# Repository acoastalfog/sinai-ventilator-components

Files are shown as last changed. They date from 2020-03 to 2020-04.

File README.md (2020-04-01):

**CURRENT VERSION: [v1.3](https://github.com/acoastalfog/sinai-ventilator-components/blob/master/v1.3). Instructions in the current version's folder should be followed, together with the supplied protocol.**

**NOTE 2020-04-01: *We have split version tracking in this project into folders. Each version contains its own `README.md` file, together with the Mount Sinai protocol, STEP, STL, and Fusion360 component files, prototyping instructions, and walk-throughs.***

# Mount Sinai Health System Split Ventilator Prototyping
The Sinai BioDesign Group at the Mount Sinai Health System is supporting ongoing work by the Department of Anesthesia's team to develop a robust and validated protocol for ventilator splitting at the Mount Sinai Hospital System. Our support is mainly in the design and prototyping of components for the split ventilator system.

Our contributions are for academic study only and we do not endorse their use in any medical application. We are making them available to the community in order to scale out prototyping and research of these components. We are making available our designs together with STEP and Fusion360 files if others choose to take what we have done and modify, and will continually update this page.

Any included protocols are not final, pose significant risks to both patients sharing a single ventilator and do not in any way reflect the normal standard of care within the Mount Sinai Health System. Protocols have not yet been trialed in patients. They are included for academic purposes and for implementation in high-fidelity human patient simulator laboratory settings.

We are following the versioning scheme developed by the Anesthesia team, and we will update the head of this document with the most up to date versions as they become available, together with paired prototyping files and instructions. Most components developed a set of valves and adapters for printing on ordinary, widely available FDM-style 3D printers, commonly found in makerspaces, institutional prototyping facilities, and home labs. Variations and opportunities to use alternate prototyping tools, and versioned branches of the protocol, will also be tracked.

## Sinai BioDesign Team Members
* Joe Borrello
* Jake Wolf
* Anthony Costa

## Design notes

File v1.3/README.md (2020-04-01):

**NOTE 2020-04-01: *We have validated the adapter components against multiple gate and needle valve configurations of the current and future protocols from the anesthesia team. Adapter components should now be printed.***

**NOTE 2020-04-01: *Added optional laser-cut plastic membrane [cut files](membrane) and [instructions](buildPlasticMembrane.md).***

**NOTE 2020-03-31: *Added detailed check valve assembly instructions [here](buildCheckValve.md).***

~~NOTE 2020-03-30: Please as of this moment only produce the one-way check-valve components until further notice. It is likely that our gate valve will change due to regulatory requirements, so adapters must be modified or may become obsolete. The check valve is independent of the gate and has been approved.~~

# Mount Sinai Health System Split Ventilator Prototyping
Version 1.3

Here, we are making available two simple-to-print flow adapters (in folder [adapter](adapter)), together with a one-way check valve (in folder [check_valve](check_valve)). The check valve is a heavily modified version of an existing open source project, with original project documentation, [build instructions](https://youtu.be/sCIX3egYKQM), and [project files](https://cad.onshape.com/documents/5c996e71d2872726995198bf/w/40c80b6ee82124a954fda09d/e/5520dc2a611624c9350b6dc1) also publicly available. We thank these teams for their effort. 

## Basic Build Information
* Both sets of parts below should be printed in PLA with a layer height between 0.1 and 0.3mm. We encourage you to print at the largest layer height possible and checking for press-fit and thread compatibility for the adapter and check valve, respectively.
* Print with at least 3 perimeters and at least 3 top and bottom layers.
* Infill of 10-20% is more than sufficient for appropriate rigidity. 
* PLA including additives *should not be used*. Other materials can be considered. PETG seems a particularly good option for dimensional accuracy, though this has not yet been tested. ABS should not be used.
* Depending on your cooling capacity you may not require any supports, but your mileage may vary. `adapter_v1.3_smallMaleMale.stl` and `valve_v1.3_Female.stl` both include a 90 degree overhang when printed in the correct orientation. Setting the overhang angle to 75 degrees will eliminate unnecessary support structures being generated for threading in each of the valve components.
* Press-fit interfaces between adapters and valves should be lined with teflon tape.

These designs have been fit tested from prints on at least 6 commonly available FDM-style 3D printers, with good intra-printer reliability. For use, prints from the same printer should be paired. The entire set of files has been parameterized around the fit of the male interface to a commonly-available [3/4" brass sweat gate valve](https://www.homedepot.com/p/Everbilt-3-4-in-Brass-Sweat-x-Sweat-Gate-Valve-170-4-34-EB/308593230).

## Inner (Male-Male) and Outer (Female-Female) Flow Adapters

**NOTE: 2020-04-01: *We have validated the adapter components against multiple gate and needle valve configurations of the current and future protocols from the anesthesia team. Adapter components should now be printed.***

~~NOTE 2020-03-30: Please do not yet produce this part. It is likely that our gate valve will change due to regulatory requirements, so adapters must be modified or may become obsolete.~~

* Files are `adapter_v1.3_largeFemaleFemale.stl` and `adapter_v1.3_smallMaleMale.stl`.
* Files should be printed in a vertical orientation, but are symmetric along this axis with a normal plane of symmetry, so either orientation is equivalent. 

## Two-Part One-Way Check Valve
* Files are `valve_v1.3_Female.stl` and `valve_v1.3_Male.stl`, and can be printed in ordinary PLA.
* Print orientation here *matters*. `valve_v1.3_Male.stl` must be printed with the threading down toward the build surface, preferably made of glass or other very smooth material. It is important that this interface is as smooth as possible.
* `valve_v1.3_Female.stl` should be printed with threads up, as this eliminates unnecessary support structures inside the thread cavity, requiring them only for the 90 degree overhang.
* Build instructions are now available as a [separate document](buildCheckValve.md).
* We include laser-cut plastic membrane [cut files](membrane) and [instructions](buildPlasticMembrane.md) as an assembly option, referenced in the build instructions for the check valve.

Appropriate orientation on the build plate is shown here.

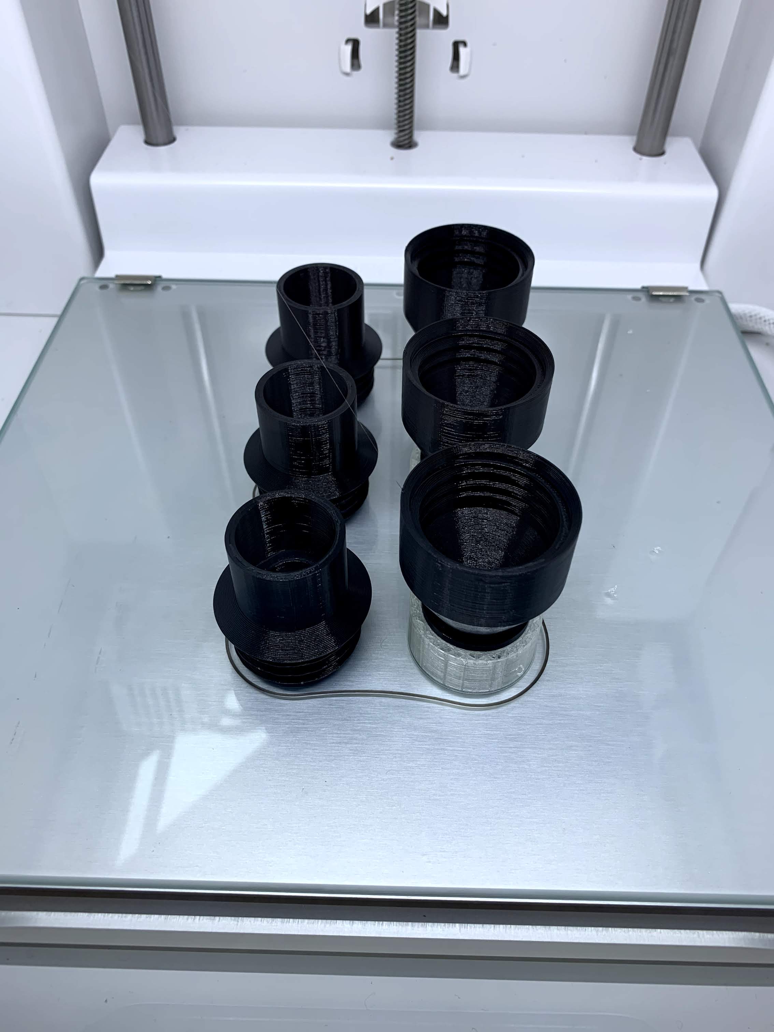
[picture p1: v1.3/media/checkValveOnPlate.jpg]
Check Valve On Glass Build Plate


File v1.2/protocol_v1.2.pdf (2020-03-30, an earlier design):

## Mount Sinai Health System Emergency Ventilator Sharing Protocol

The protocol described in this document is a work in progress and is subject to revision

Version 1.2
Version Date: March 28, 2020

Protocol Developed By:
Martin Chen MD
Anjan Shah MD
Ronak Shah MD
George Zhou MD
Erica Kane MD, MPH
Garrett Burnett MD
Chang Park MD
Daniel Katz MD
Shams Ranginwala MBA, RRT-NPS, CPFT
Matthew Levin MD

We would like to acknowledge the team and protocol developed at Columbia/NYP which served as a template and guide for this document.

Purpose: This document describes the implementation of a shared (also referred to herein as split) ventilator protocol for the Mount Sinai Health System (MSHS). It would be utilized when enacting Crisis Standards of Care at hospitals within the MSHS, when rescuable patients who require mechanical ventilation would otherwise be denied ventilation due to lack of available ventilators. This protocol poses significant risks to both patients sharing a single ventilator and does not in any way reflect the normal standard of care within the MSHS. It has been developed in response to the unique situation caused by the COVID-19 Crisis in New York City. Each patient should be mechanically ventilated individually, unless the supply of ventilators is completely exhausted and the patient would otherwise be expected to die.

Version 1.2 2020-03-29 | 1

DISCLAIMER: This shared ventilator protocol has not yet been trialed in patients. The study was designed and conducted in the Department of Anesthesiology, Perioperative and Pain Medicine’s high-fidelity human patient simulator laboratory using two CAE HPS Anesthesia Simulator Mannequin Systems (CAE Healthcare, Sarasota, Florida). The parameters were determined experimentally.

Patient selection: Criteria for split ventilation will likely be adaptive given the emergent circumstances, but if possible the following criteria should be satisfied:
1. Both patients are Covid-19 patients, in order to avoid infection.
2. Patients should be paired according to ideal body weight.
3. Patients should have initial similar lung compliances and levels of ventilatory support
4. Patients should require similar levels of PEEP.
5. Patients should be predicted to require mechanical ventilation with paralysis for > 72 hours.

Design Overview: The ventilator breathing circuit is split using standard T-pieces and connectors. On the inspiratory limb, two standard ¾” brass lead-free gate valves (normally used in plumbing applications) are placed in-line on either side of a T-piece. The connections on the ¾” valve have an internal diameter (ID) of approximately 22 mm. On the expiratory limb, two unidirectional valves are placed on two sides of another T-piece. Near the patient, a standard spirometry sensor is placed in-line between the endotracheal tube elbow and the wye connector of the breathing circuit. The sensor is connected to the gas analyzer-spirometry module of a portable or stationary physiologic monitoring system . Due to the nature of the pandemic, a bacterial/viral (B/V) filter is placed between the elbow and the endotracheal tube, and additional B/V filters are placed between the circuit and the inspiratory and expiratory connection ports on the ventilator.

Improvements over other solutions:
1. The ¾” gate valves allow the pressure and volume delivered to each patient to be adjusted and titrated to account for the potentially different lung compliance (stiffness) of each patient.

2. The use of appropriately placed spirometry sensors enables more accurate measurement of the delivered tidal volume and pressures for each patient individually. Spirometry and gas analysis data can be displayed on a wall-mounted or portable monitor, provided that a spirometry-gas analyzer module can be installed in the physiologic monitoring system.
3. The unidirectional valves in the expiratory limbs prevent reverse flow of gas in the circuits.

The ¾” valves used are brass, lead-free standard plumbing valves that are certified for use in domestic water supply applications. These brass valves are heavy, so ensure that the connections are gas-tight using teflon tape and secure the valves to the ventilator.

DISCLAIMER: The use of these valves for a medical application is not approved in any way and is a significant deviation from standard of care. The valves MUST be cleaned to remove obvious manufacturing contaminants such as oil, grease, dirt, etc. Our protocol was to clean by hand using soap and a brush, then place through a steam sterilization cycle. As per CDC guidelines, peracetic acid and hydrogen peroxide should be avoided due to the issue of brass corrosion.

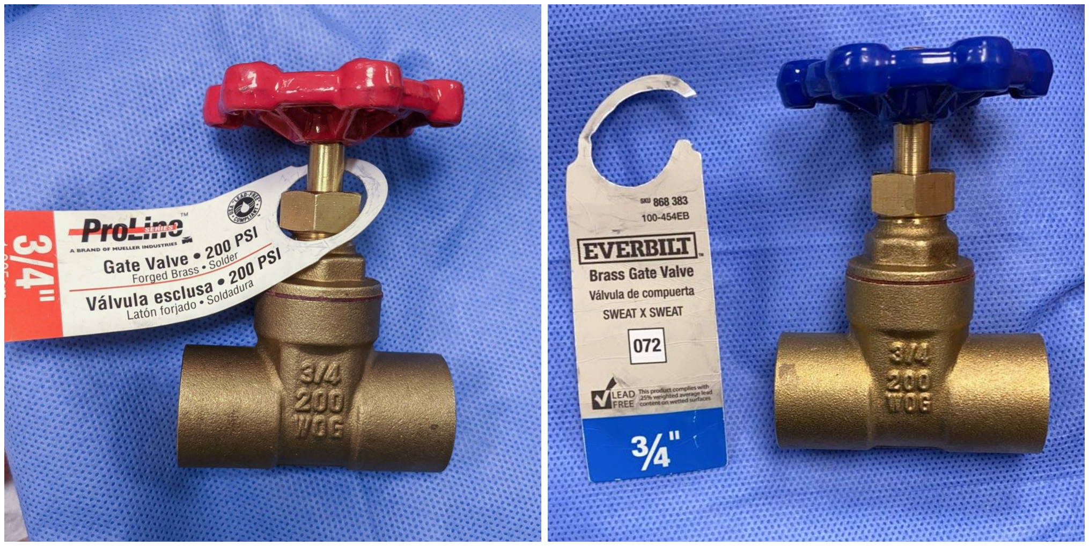
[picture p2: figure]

Figure 1A - Part #1, listed below. Example ¾” brass gate valves with solder/sweat connections. PVC alternatives are available, but were not tested due issues with valve performance.

Parts List
1. 2x ¾” ID lead-free brass gate valves with “sweat” or “solder” connections for the inspiratory limbs. These should be available from Home Depot, Lowes, or any plumbing supply store.
2. 2x in-line, unidirectional valves for breathing circuit’s expiratory limbs (Mallinckrodt One-way valve, 22mm F x 22mm M)
3. 2x T-pieces, 15mm ID/22mm OD to 2x 19mm ID/22mm OD (Hudson RCI Trache Tee Oxygenator)
4. 4x 22mm OD, 15 mm ID both ends (male-to-male) adapter (blue Airlife Intubation Adapter 001820)
5. 2x 22mm ID female-to-female adapter (clear Mallinckrodt Universal Cuff Adapter)
6. 2x ventilator circuits
7. 2x yellow spirometry sensor and tubing (GE D-lite++ patient spirometry set; GE part number 2102497-002- 3 meter length tubing)
8. 2x Bacterial/Viral (B/V) filters (placed near ETT and in expiratory limb)
9. 2x Heat and Moisture Exchanger Filters (HME Filter)
10. Spirometry module/monitor (GE Carescape Respiratory Module)
11. Teflon plumbing threadseal tape (required for metal joints)
12. Electrical tape

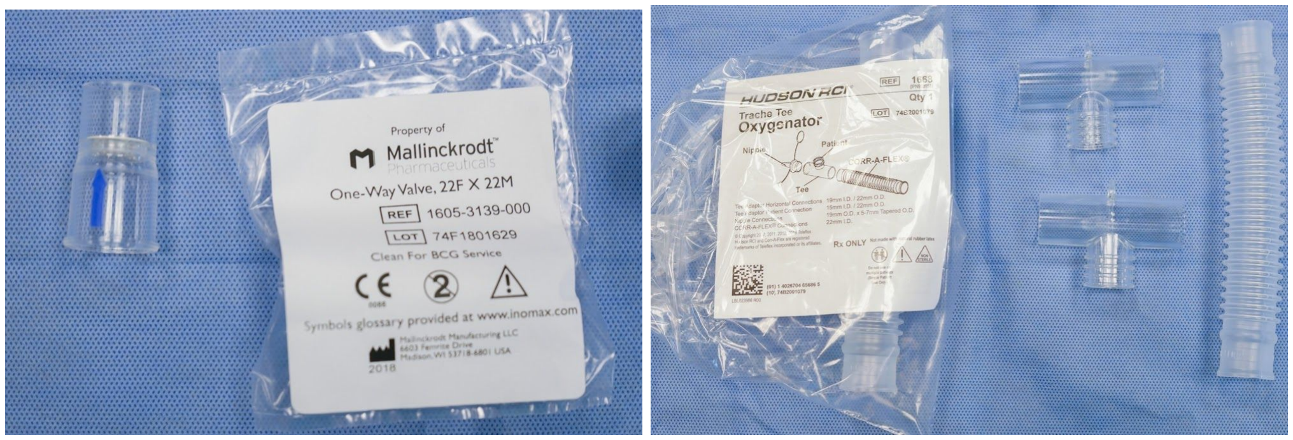
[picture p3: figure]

Figure 1B. Part #2 and #3, listed above.

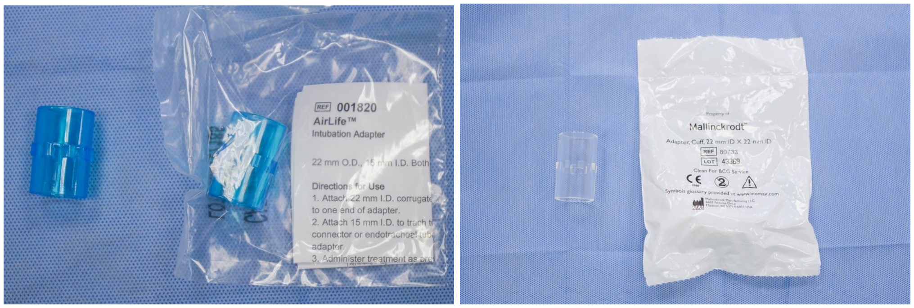
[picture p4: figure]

Figure 1C. Part #3 and #4, listed above.

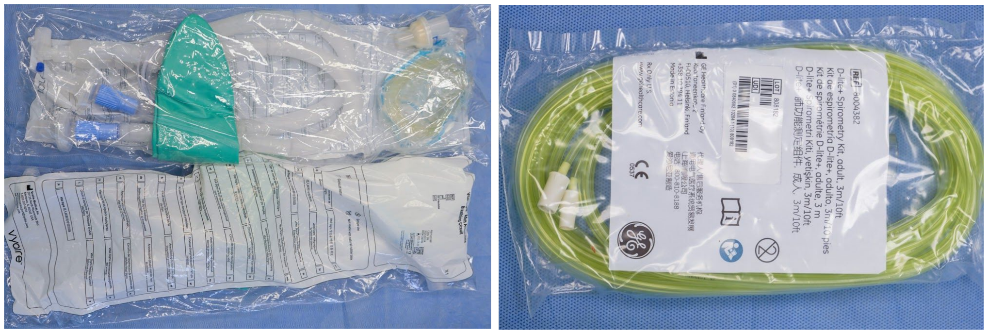
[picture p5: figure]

Figure 1D. Part #6 and #7, listed above.

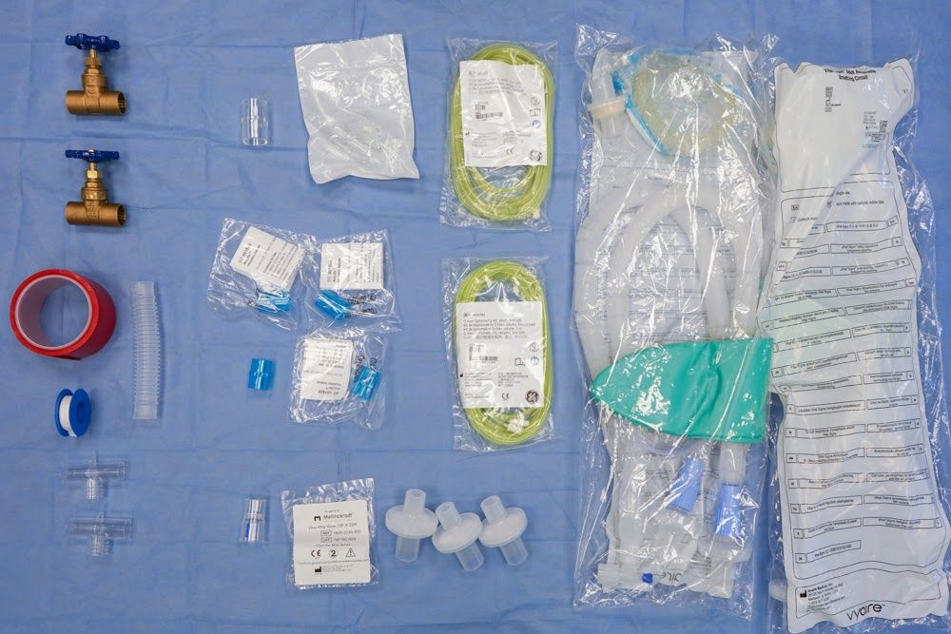
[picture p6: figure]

Figure 1E. All parts needed for the dual circuit. Note brass gate valves in upper left.

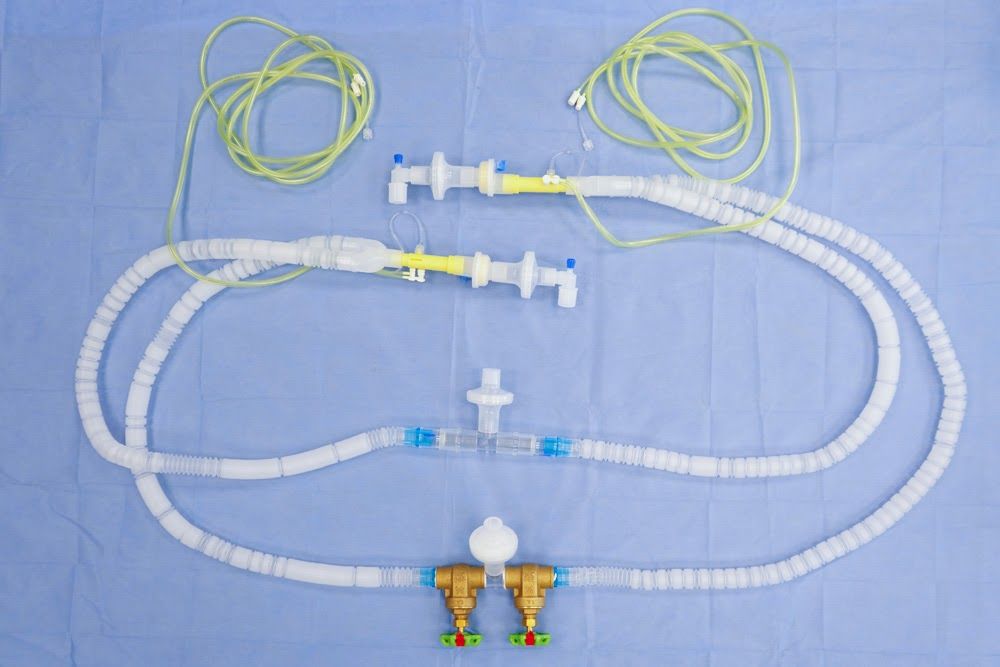
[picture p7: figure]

Figure 2 - All assembled parts.

Circuit Assembly
Inspiratory limb: Vent Inspiratory connection → Viral filter (optional) → 22mm T- piece* with distal limbs wrapped with teflon tape, then to each side of T piece: → ¾” brass gate valve → 22mm OD male-to-male adapter wrapped with teflon → inspiratory limb of circuit → wye piece

*Wrap T-piece -to- brass valve connection with electrical tape to ensure gas-tight seal and to prevent disconnection

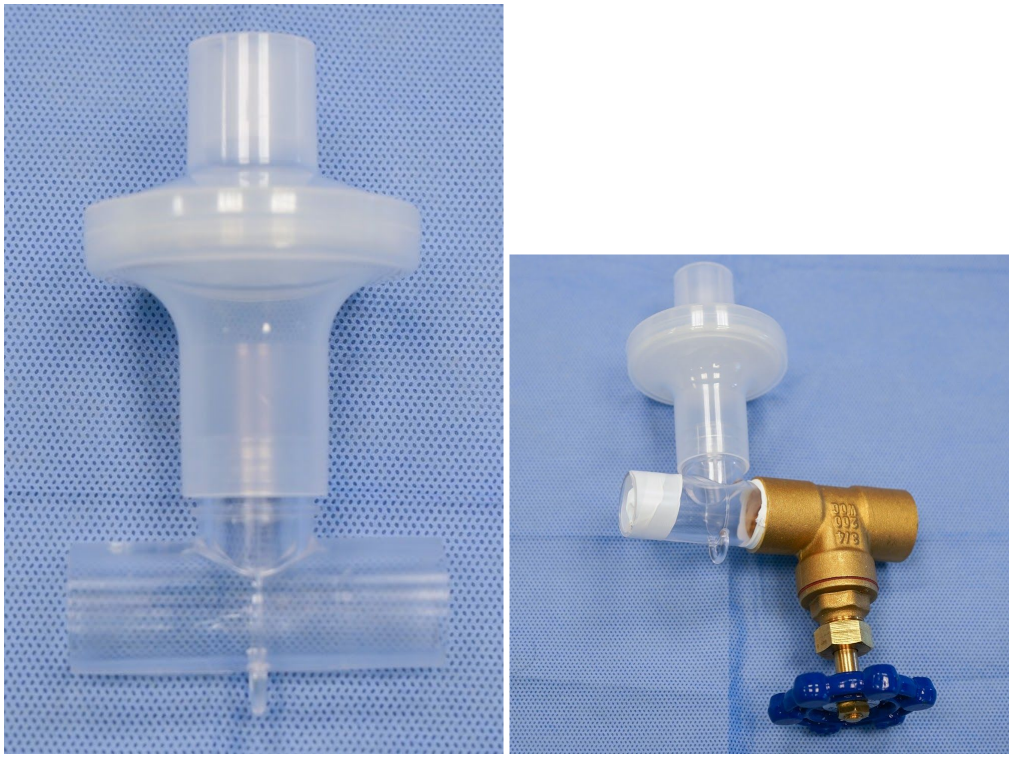
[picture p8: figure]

Figure 3 - Partially assembled inspiratory limb. Gate valve has been attached to one limb of the T-piece using Teflon tape for snug fit. Filter on the T-piece stem will connect to the ventilator inspiratory port.

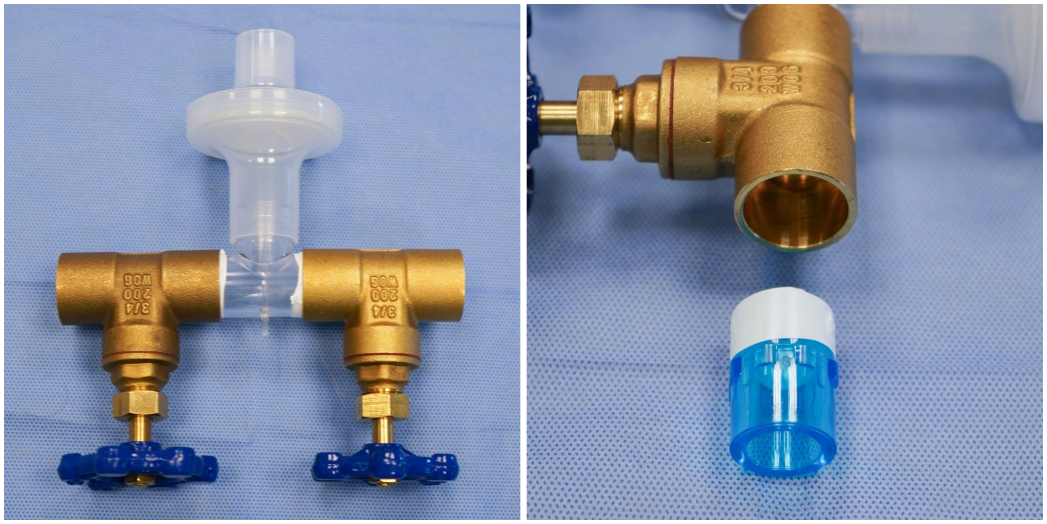
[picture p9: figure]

Figure 4 - both gate check valves have now been installed. 22 mm OD blue male-male adapter with teflon tape ready to be inserted into the gate check valve.

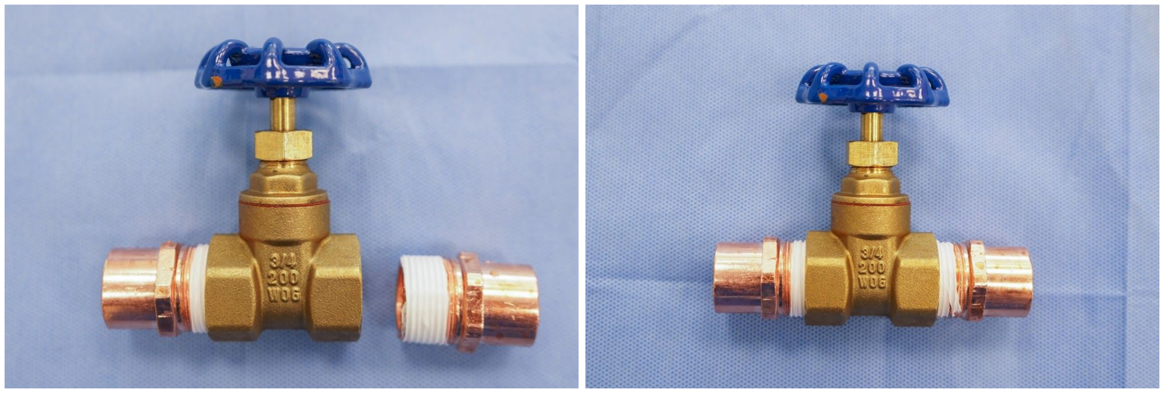
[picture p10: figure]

Figure 5 - Alternatively, ¾” lead free brass gate valves with thread connections can be used for the inspiratory limb. If a threaded connection is used, an additional ¾” thread-to-sweat connection on both sides is needed. Teflon tape is used once again to create a proper seal between the threaded brass gate valve and the copper connection. The 22 mm OD blue male-male adapter with teflon would then be inserted into the sweat connection on both sides.

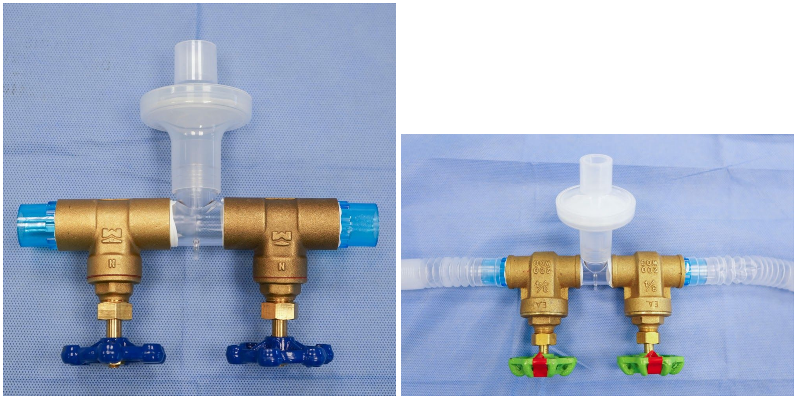
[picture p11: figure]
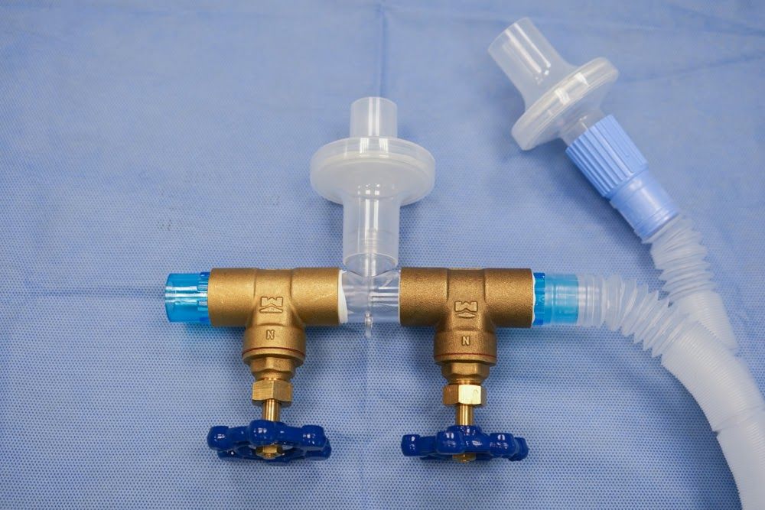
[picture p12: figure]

Figure 6 - inspiratory limb of breathing circuit is connected to 22 mm OD blue male-male adapter. With this particular circuit, the included B/V filter and blue connector can be optionally disconnected or rearranged to optimize circuit ergonomics and minimize circuit leaks. It is important to keep the connection to the inspiratory port of the ventilator short, due to the weight of the gate check valves.

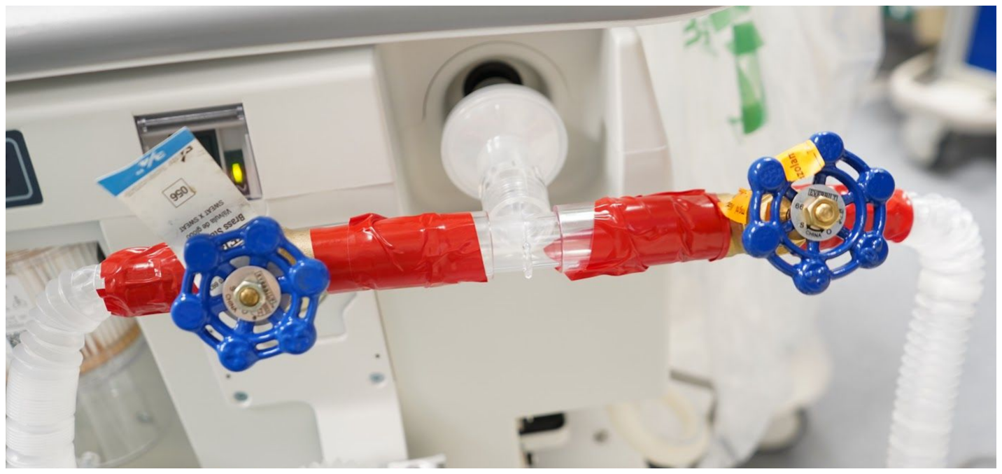
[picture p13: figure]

Figure 7 - Assembled Inspiratory Gate Check Valves. Note: red electrical tape used to provide structural support, and colored labeling tape has been added to the valve on the right to indicate orientation.

Patient Connection: ETT -> elbow connector → Viral filter → HME filter → yellow spirometry sensor →patient wye. Make one for each patient.

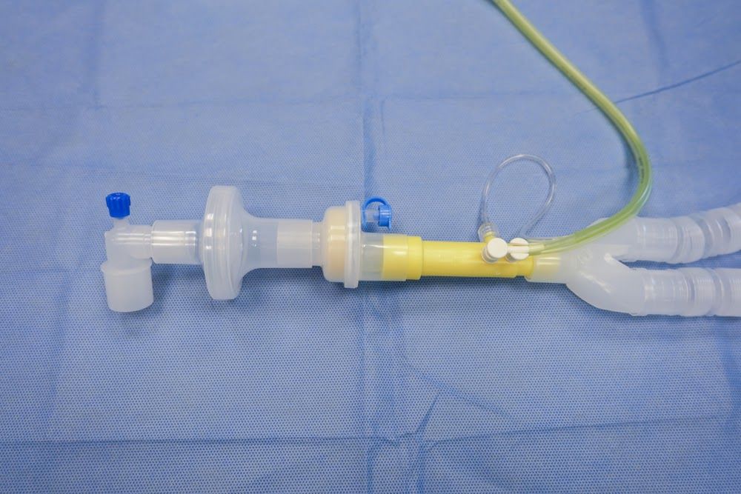
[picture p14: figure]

Figure 8 - Assembled patient connection with (left to right): elbow, Bacterial/Viral filter, HME filter, spirometry tubing, and circuit wye connector. Note that one of these is necessary for each patient.

Expiratory limb: | expiratory circuit tubing → 22mm OD male-to-male adapter →
one-way-valve (22mm ID to 22mm OD) → | 22mm ID female-to-female adapter | → 22mm
T-piece → B/V filter → Vent expiratory return connection

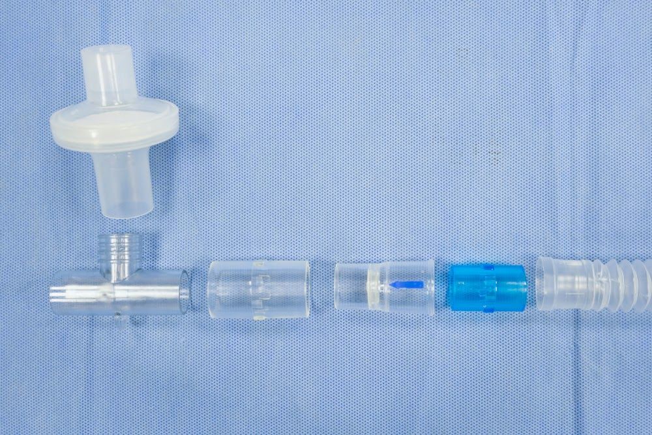
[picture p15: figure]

Figure 9 - Components of Expiratory Limb.

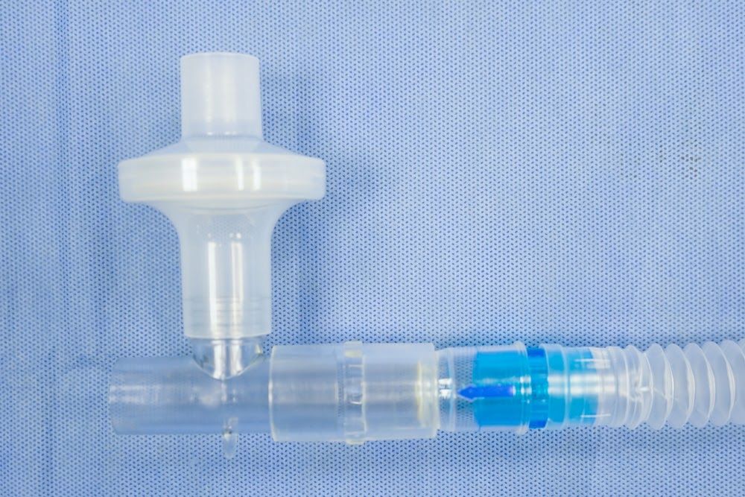
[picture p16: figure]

Figure 10 - Assembled expiratory limb, one side only.

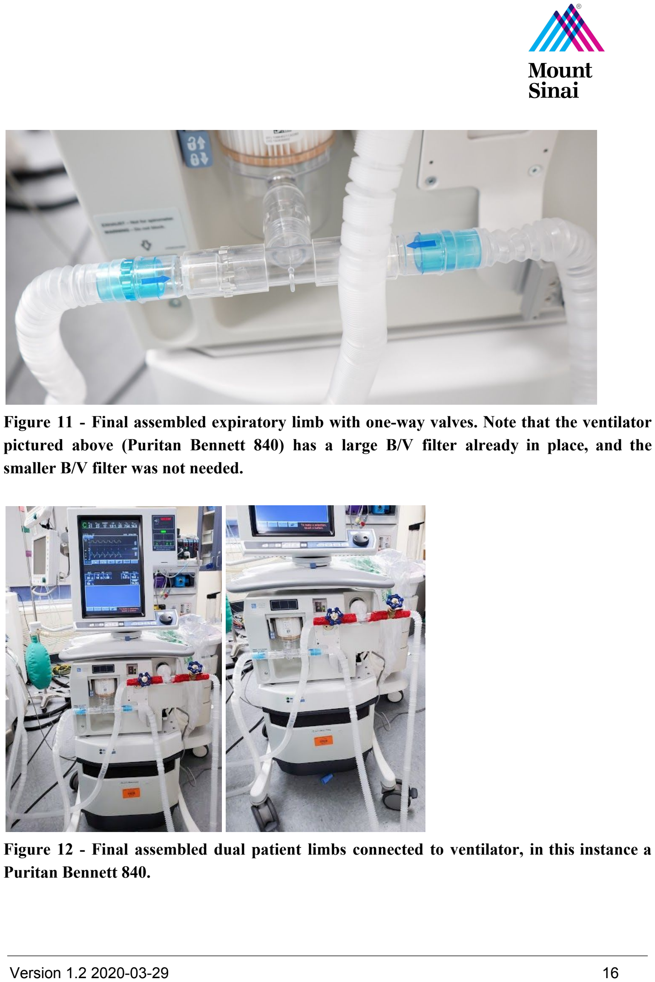
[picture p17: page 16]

Figure 11 - Final assembled expiratory limb with one-way valves. Note that the ventilator pictured above (Puritan Bennett 840) has a large B/V filter already in place, and the smaller B/V filter was not needed.

Figure 12 - Final assembled dual patient limbs connected to ventilator, in this instance a Puritan Bennett 840.

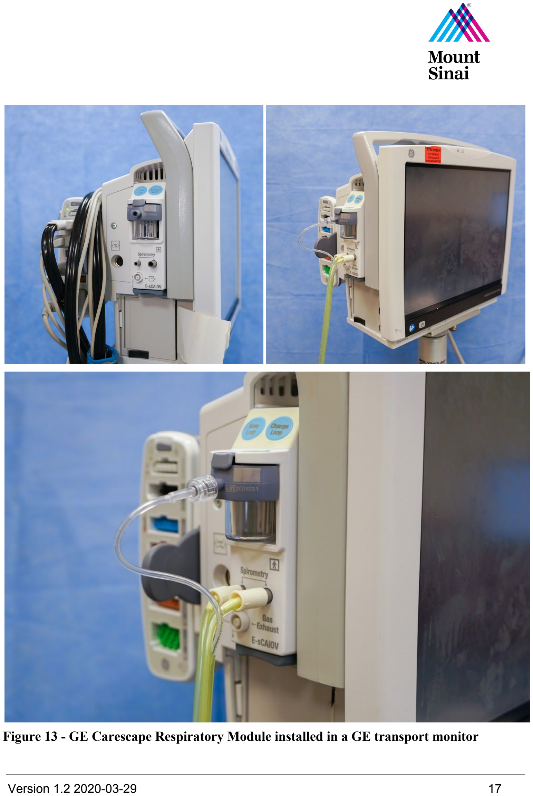
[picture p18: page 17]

Figure 13 - GE Carescape Respiratory Module installed in a GE transport monitor

Using the Dual-Patient Ventilation Setup
Initiation
The ventilator and circuit should be prepared, and usual system checks should be run. Prior to initiating mechanical ventilation the ¾” brass gate valves should be closed completely and then turned one revolution (360 degrees) open. We have found that these valves provide variable, but not linear, resistance to inspiratory flow that is useful when the valves are opened in the range of 120-360 degrees from the fully closed position, although this may vary depending on manufacturer and should be validated before use. Many ventilators will give an error alert during the leak test. In this case double-check all connections and consider re-running the circuit test with only one circuit attached. The tidal volume estimated by the ventilator may be inaccurate during two circuit ventilation, necessitating individual tidal volume assessment by spirometry.

Management
Split ventilation, as described in this document, should be exclusively used for paralyzed patients ventilated in assist control pressure control mode. Paralysis is important to avoid rapid changes in lung compliance that could affect ventilation of the other patient and the system described herein has only been validated under these conditions. Pressure control should be optimized with the average best PEEP for both patients (Use clinical judgement on the appropriate PEEP that both patients can tolerate) and an initial driving pressure and inspiratory time on the ventilator which provides 4-6cc/kg ideal body weight to the least compliant patient (patient A). Thereafter the driving pressure for the more compliant patient (patient B) should be decreased by turning the ¾” brass gate valve slowly clockwise until tidal volumes for patient B decrease and are also in the 4-6cc/kg ideal body weight range, to avoid further lung injury from volutrauma and/or barotrauma. These parameters were determined experimentally in our anesthesia high-fidelity human patient simulator laboratory using two CAE HPS Anesthesia Simulator mannequin systems (CAE Healthcare, Sarasota, Florida) connected to the dual circuit and a Puritan-Bennett 840 series ventilator. We further confirmed these results using an anesthesia workstation mechanical ventilator (GE Aisys, Louisville, KY). With the GE Aisys ventilator, despite low fresh gas flow rates (1 liter/minute), the ventilatory parameters for both high-fidelity simulators remained the same (including tidal volume and peak airway pressures).

Monitoring

Ideally, clinicians should continuously monitor each patient for adequacy of ventilation using in-line spirometry that measures inspired (and expired) tidal volume, peak airway pressure, and total thoracic compliance. Continuous monitoring is preferred for patient safety and to limit unnecessary exposure of staff due to circuit disconnects. If continuous spirometry is unavailable, these parameters should be assessed and recorded at least every 4 hours for each patient, or when continuously monitored vital signs (i.e., SpO2) demand additional investigation. Routine sampling of arterial blood for gases should be analyzed to ensure adequacy of ventilation and gas exchange, as available. It is not expected that ventilation for both patients can be optimized. Both patients will receive the same PEEP and FiO2

. Do not attempt to use gate-check valves in the expiratory limb as a method of controlling PEEP, this has not been fully tested in the simulation lab. See Appendix A for details. Respiratory acidosis is tolerated. Lung injury results from prolonged exposure to FiO2 > 60% (24 hours on 100% FiO2 will begin to cause injury), and from PIP > 30-35 cmH2O (volutrauma), but not carbon dioxide or acidosis toxicity. The presence or absence of acidosis is immaterial and permissive hypercapnia is the norm when using smaller tidal volumes < 6 ml/kg.

EKG, BP, SpO2, and other routine monitoring should continue as per ICU standards.

Discontinuation
Split ventilation should be discontinued immediately upon availability of enough ventilators to ventilate each patient independently, or in the event that ventilator weaning is to be attempted and prior to the discontinuation of deep sedation and paralysis. It should also be discontinued if either patient does not tolerate split ventilation. Additional ventilators, either portable or otherwise, should be immediately available in case of an emergency.

Alarm Parameters
Due to the unique nature of this ventilator setup, it is crucial to monitor each patient’s ventilatory parameters in addition to the ventilator, with alarms tailored to each patient and group of co-ventilated patients. This section details the alarm configuration by machine:

Ventilator Alarms
Tidal Volume Alarm: This must be set up appropriately to ensure that a kink in any limb of the circuit, a circuit disconnect, or a change in patient physiologic parameters is quickly identified. The alarms should be configured so that the minimum tidal volume is equal to the expected tidal volume of Patient A + Patient B minus 20%, and the maximum tidal volume is the expected volume plus 20%.

Pressure Alarms: The peak airway pressure alarm, generally set at 40cm H2O, is appropriate for this setup. Peak pressures > 40cm H2O could indicate circuit obstruction, most likely at the level of the gate valves.

Sample Alarm Configuration
| Patient 1 (IBW 70kg) | Patient 2 (IBW 70kg) | Ventilator
Tidal Volume Minimum (4cc/kg)-10% | 252cc | 252cc | 504cc
Tidal Volume Max (4cc/kg)+10% | 308cc | 308cc | 616cc
Minute Ventilation Min (4cc/kg * 20/min) -20% | 4.5L/min | 4.5L/min | 9L/min

IBW= Ideal Body Weight

Verify that alarms are audible. Standard monitors, such as SpO2, EKG, and blood pressure should all be active as per unit standard, and preferably visible from outside the room. FiO2 and EtCO2 alarms should all be active and easily visible.

Respiratory Module/Spirometry Alarms

References:
1. Smith R, Brown J. Simultaneous ventilation of two healthy subjects with a single ventilator. Resuscitation. 2009;80(9):1087. doi:10.1016/j.resuscitation.2009.05.018 (https://doi.org/10.1016/j.resuscitation.2009.05.018)
2. Amato M, Meade M, Slutsky A, et al. Driving pressure and survival in the acute
respiratory | distress | syndrome. | N | Engl | J | Med. | 2015;372(8):747-755.
doi:10.1056/NEJMsa1410639 (https://doi.org/10.1056/NEJMsa1410639)
3. Branson R, Blakeman T, Robinson B, Johannigman J. Use of a single ventilator to support 4 patients: laboratory evaluation of a limited concept. Respir Care. 2012;57(3):399-403. doi:10.4187/respcare.01236 (https://doi.org/10.4187/respcare.01236)
4. Carvalho P, Thompson WH, Riggs R, Carvalho C, Charan NB. Management of bronchopleural fistula with a variable-resistance valve and a single ventilator. Chest. 1997 May;111(5):1452-4. PMID: 9149613
5. Charan NB, Carvalho CG, Hawk P, Crowley JJ, Carvalho P. Independent lung ventilation with a single ventilator using a variable resistance valve. (https://www.ncbi.nlm.nih.gov/pubmed/7813287) Chest. 1995 Jan;107(1):256-60. PMID: 7813287
6. Neyman G, Irvin CB. A single ventilator for multiple simulated patients to meet disaster surge. Acad Emerg Med. 2006 Nov;13(11):1246-9. Epub 2006 Aug 2. PMID: 16885402
7. Rutala WM, Weber DJ. Guidelines for Disinfection and Sterilization in Healthcare Facilities. Centers for Disease Control. 2008. 1-158.

Appendix A
An experiment with two additional ¾" brass valves attached to the expiratory limb of each patient was performed to determine if individualized PEEP could be delivered to each patient using these valves. The results showed that incrementally closing the ¾" valve in the expiratory limb of patient A until almost fully closed (while keeping the valve on patient B wide open), resulted in no significant increase in PEEP to Patient A (from baseline intrinsic system PEEP of 7cm H2O to an increase of 8 cm total), and in fact led to additional negative events:
- Rise in observed end- tidal CO2
on monitor of patient A
- Gradual overall decrease in total system volume with decrease in observed tidal volume of patient B.

Version History:
1.0 - Initial version March 26 2020
1.1 - March 27, 2020 Clarify that gate valves cannot be used in the expiratory limb. Add Appendix A with details of why this is not advised. Add Disclaimer. Clarify that respiratory acidosis is tolerated and not inherently dangerous.
1.2 - Add disclaimer regarding the brass valves. Make disclaimer text Red. Update pictures with higher resolution. Clarify language in Appendix A. Add suggested Alarm Parameters and results of alarm testing.

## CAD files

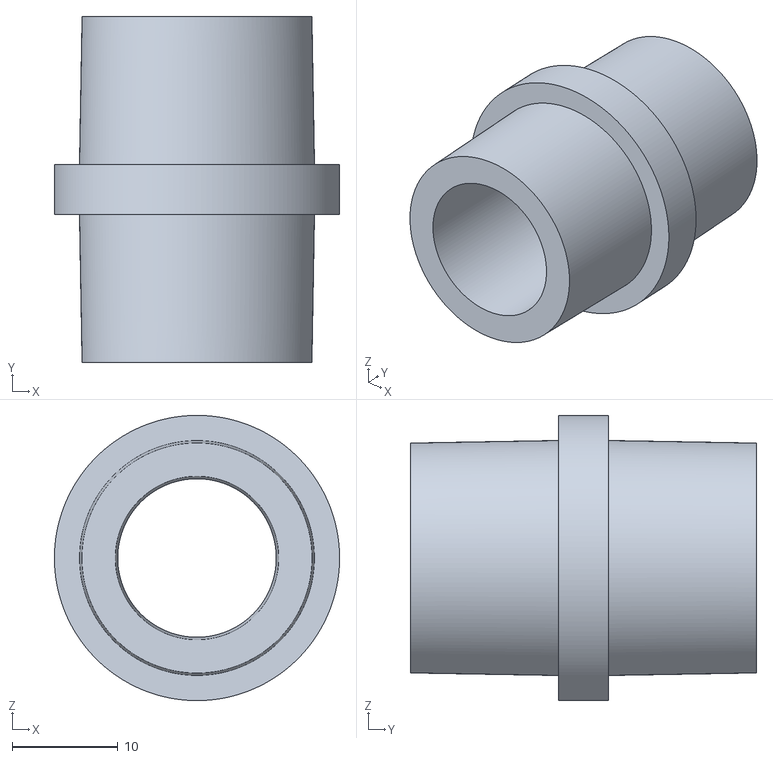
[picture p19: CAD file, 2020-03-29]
v1.3/adapter/adapter_v1.3_smallMaleMale.stl
27.0 x 32.8 x 27.0

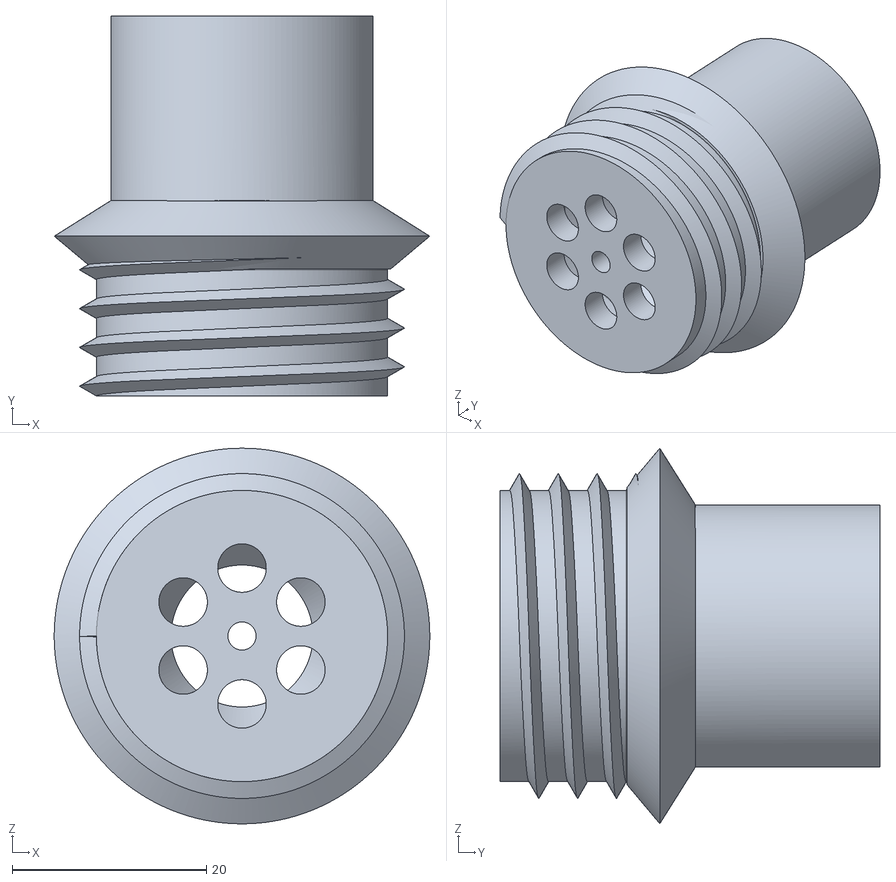
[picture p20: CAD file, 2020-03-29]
v1.3/check_valve/valve_v1.3_Male.stl
38.7 x 39.2 x 38.7

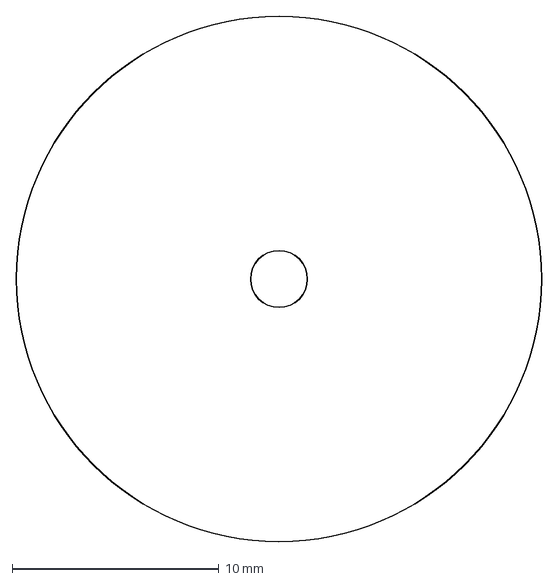
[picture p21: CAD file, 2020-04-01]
v1.3/membrane/plasticValveMembrane_v1.3.dxf
25.4 x 25.4 mm

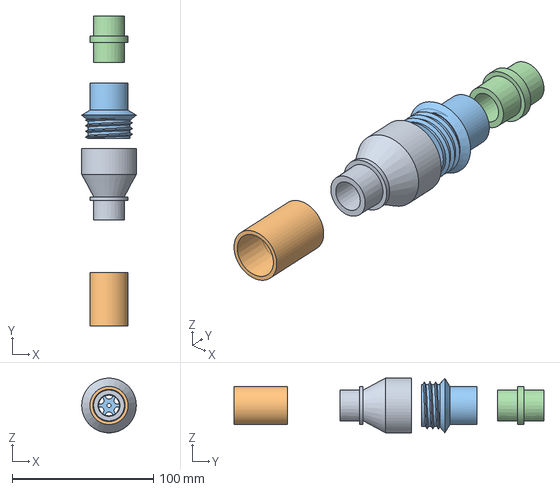
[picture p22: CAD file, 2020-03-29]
v1.3/ventilator_components_v1.3.step
38.7 x 219.3 x 38.8 mm
Check Valve - Part 2 v1

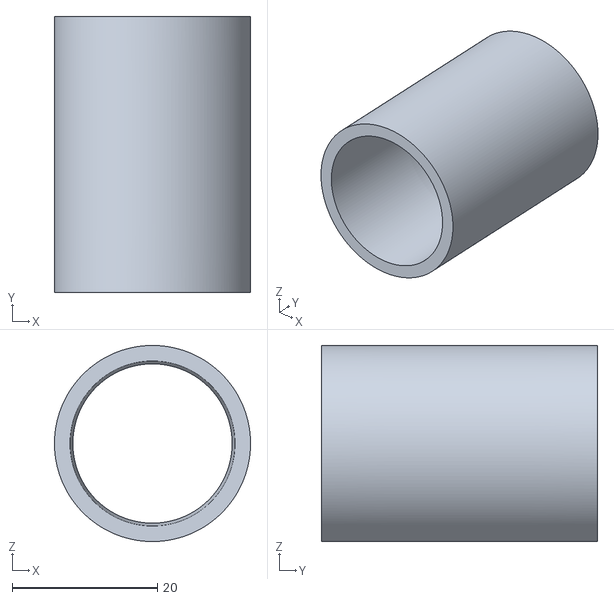
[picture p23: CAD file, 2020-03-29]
v1.3/adapter/adapter_v1.3_largeFemaleFemale.stl
27.0 x 38.0 x 27.0

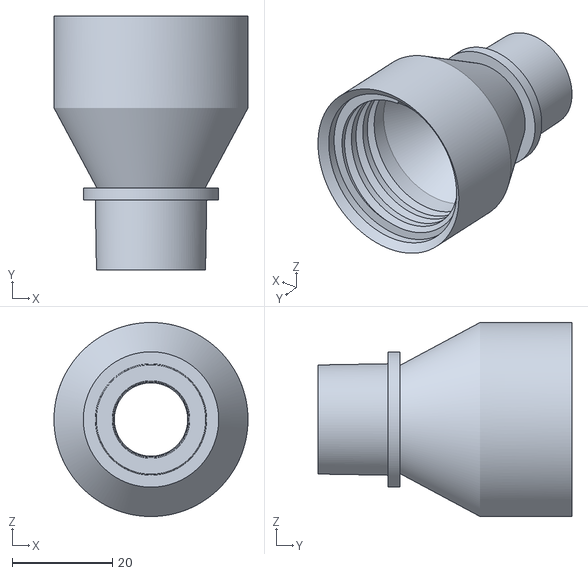
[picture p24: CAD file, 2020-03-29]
v1.3/check_valve/valve_v1.3_Female.stl
38.7 x 50.7 x 38.7

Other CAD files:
v1.3/ventilator_components_v1.3.f3d

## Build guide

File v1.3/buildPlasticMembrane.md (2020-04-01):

**NOTE 2020-04-01: *This process has only been validated on a Glowforge Basic laser cutter (40W CO2 laser); However, many of these parameters translate exactly to the corresponding parameters used by Epilog and Universal laser cutters (40W-60W range, CO2 lasers).***

## Build Instructions for Laser Cutting Plastic Bag Membrane

1. Load `plasticValveMembrane_v1.3.dxf` or `plasticValveMembrane_v1.3.svg` into the vector editing software of your choice.
2. Ensure the diameter of the larger circle is 1 in. Scale the drawing uniformly if needed.
3. Change the drawing fill, stroke width, and stroke color to ensure it is cut (not scored, etched, or rastered) on the laser cutting system being used.
4. Once the necessary drawing edits have been made, adjust the cutting parameters of the laser to the following:
    * Full speed
    * 35% - 45% of max power (lower percentage for higher powered lasers and vice versa)
    * Max frequency/PPI
5. Lay a standard plastic storage bad (sheet thickness ~0.0025in) flat on the laser cutter bed and hold taut with masking tape, pins, or magnets. See image below.
6. Ensure the laser cutter is properly focused and begin cutting.

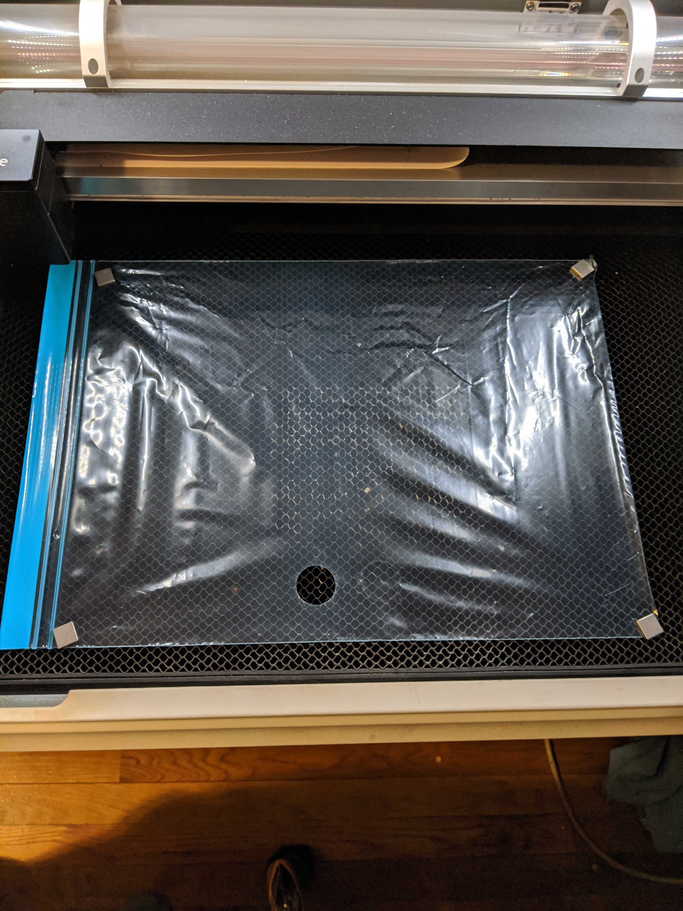
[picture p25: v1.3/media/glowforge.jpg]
Half Cut Plastic Bag, Laid Out Flat and Taut on Laser Cutter


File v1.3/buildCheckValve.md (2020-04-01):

## Check Valve Build Instructions
### Bill of Materials
* Paired, 3D printed check valves
* Ziploc sandwich bags
* Short (<20mm) M3 screws
* PTFE (Teflon) tape
* Scisors
* Awl, or equivalent
* Allen wrenches (or appropriate  wrench for M3 screw above)

### Instructions

1. Prepare the male valve component for an M3 screw by using an awl or similar cylindrically-shaped tool to slightly widen the central screw socket.

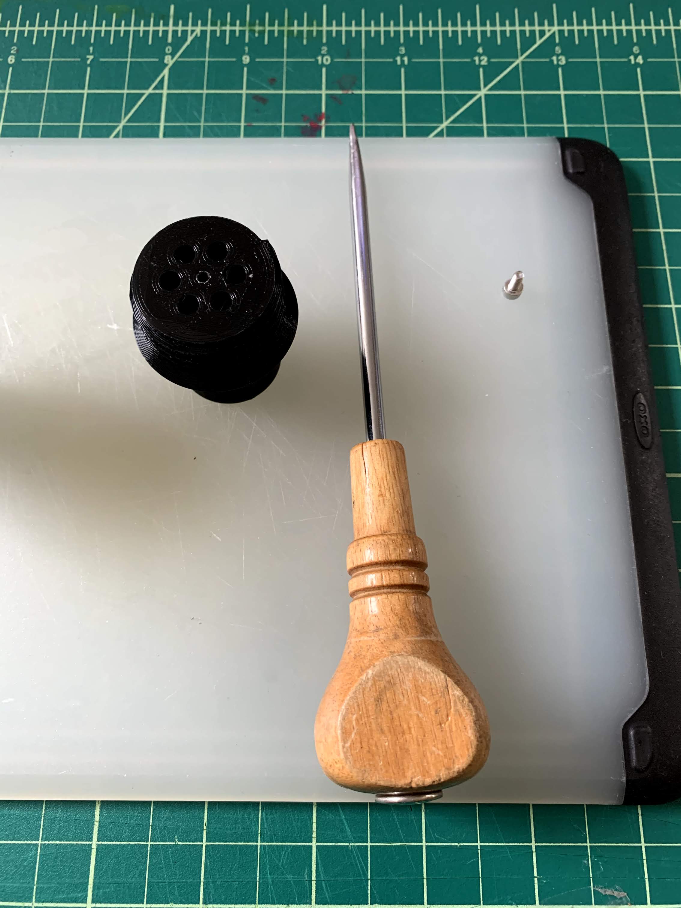
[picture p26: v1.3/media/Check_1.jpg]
Male Adapter, Awl, and Short M3 Screw


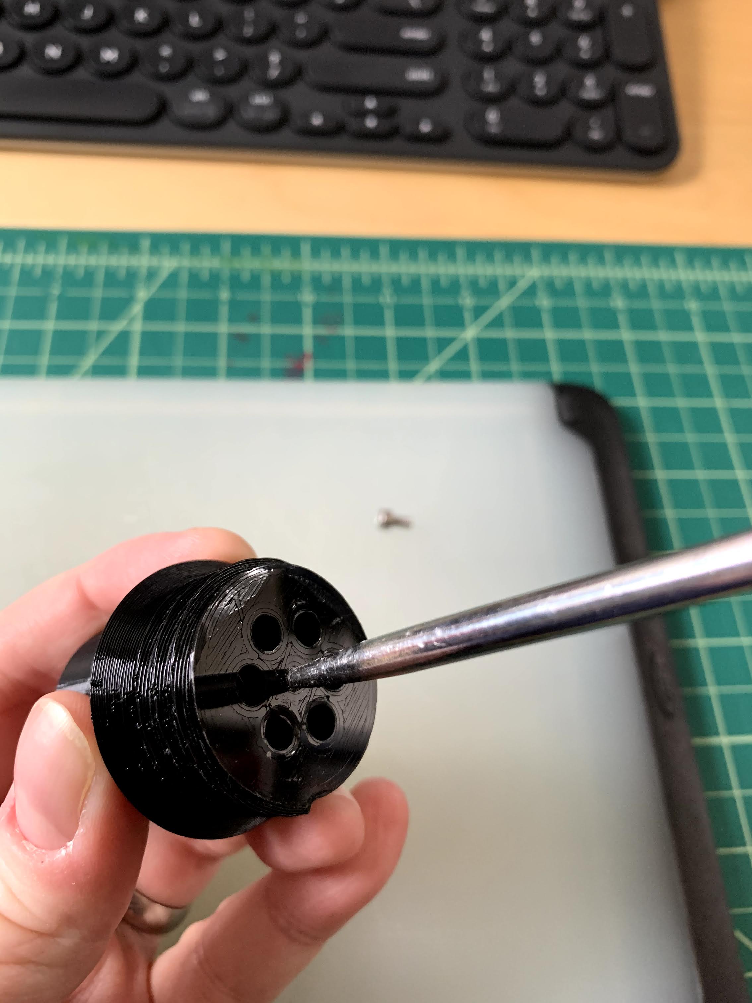
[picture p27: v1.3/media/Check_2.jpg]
Widen Outer Male Adapter Socket


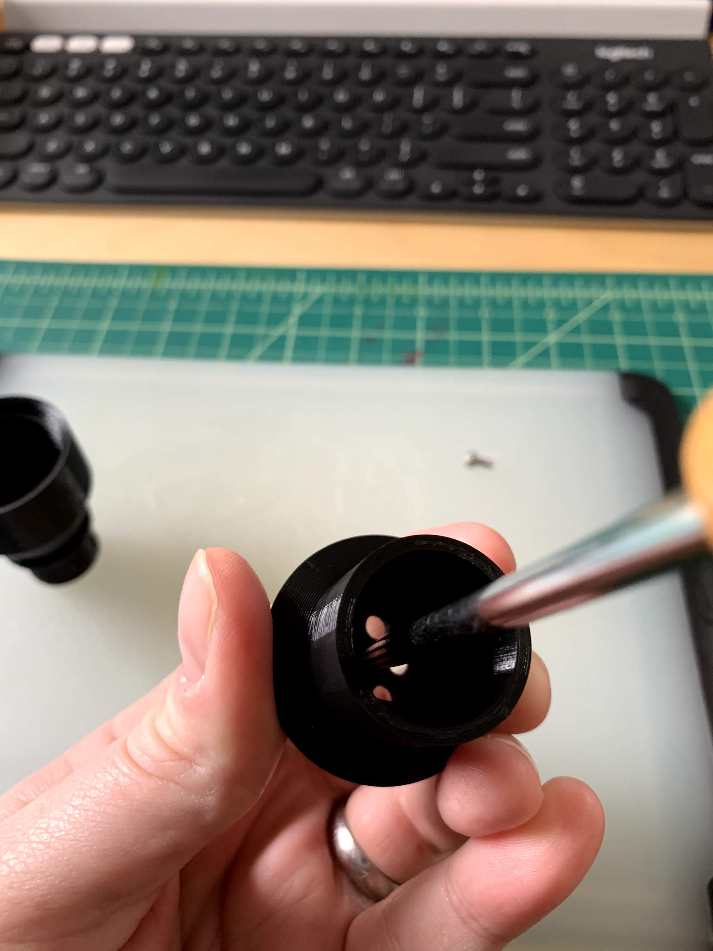
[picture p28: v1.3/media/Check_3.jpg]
Widen Inner Male Adapter Socket


2. Using a standard Ziploc or equivalent sandwich bag, cut a single layer of plastic material large enough to entire cover the surface of the male valve component. Alternatively, you may use the optional laser-cut plastic membrane [cut files](membrane) and [instructions](buildPlasticMembrane.md) to create a precision membrane from standard Ziploc bags.

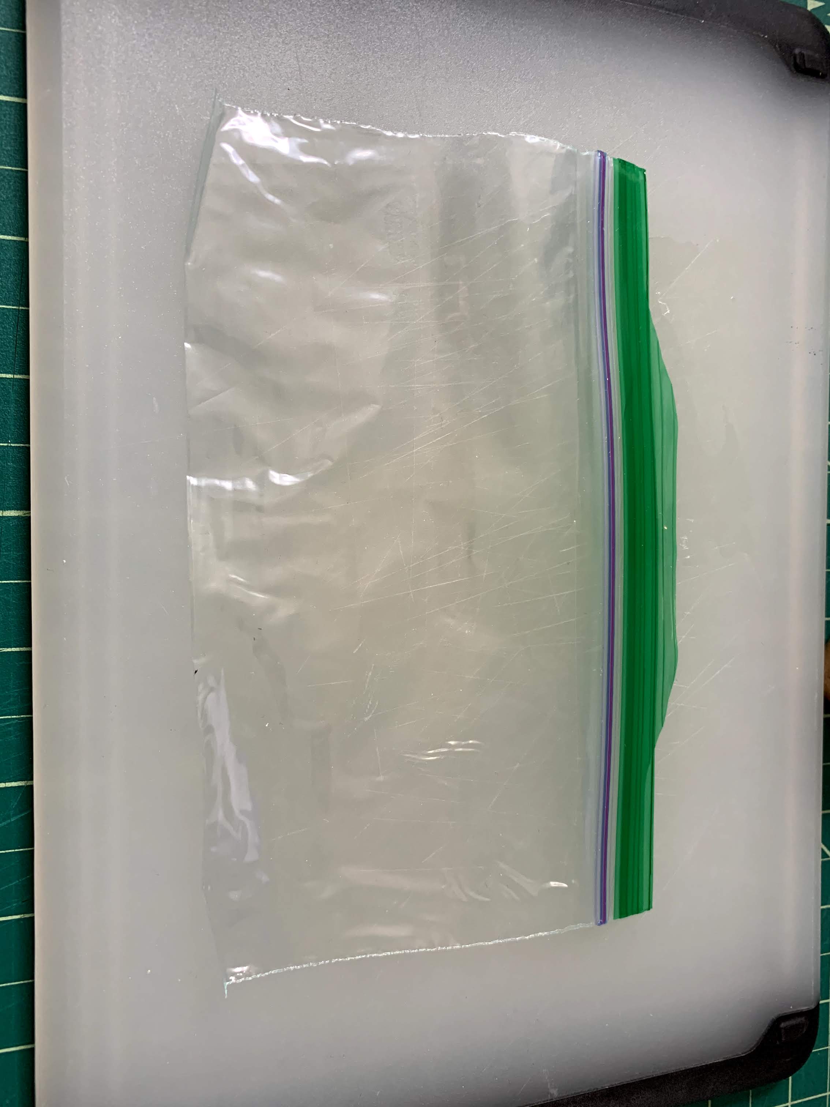
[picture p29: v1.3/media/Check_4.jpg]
Ziploc Sandwich Bag


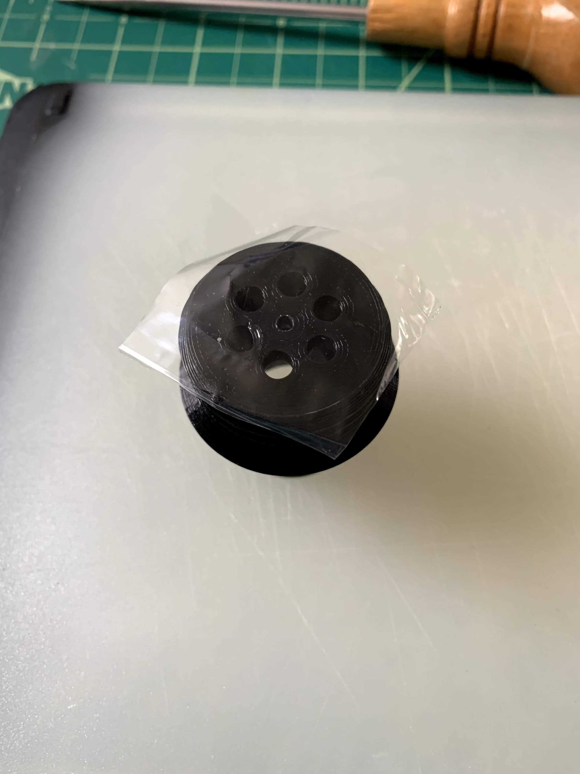
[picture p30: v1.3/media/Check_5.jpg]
Cut Bag Layer


3. Using your awl or equivalent device (a  stab incision into the plastic will also work), create a hole in the center of the Ziploc plastic sheet through which the screw will be inserted. Ensure the size of the hole is at a minimum, no wider than the central screw socket on the component itself.

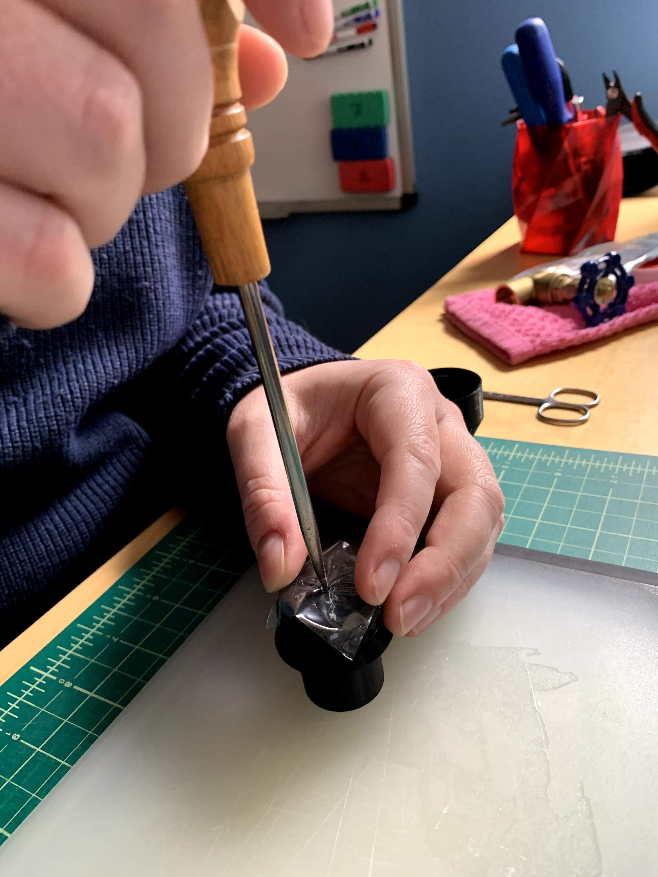
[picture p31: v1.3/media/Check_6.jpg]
Create Screw Hole in Sandwich Bag


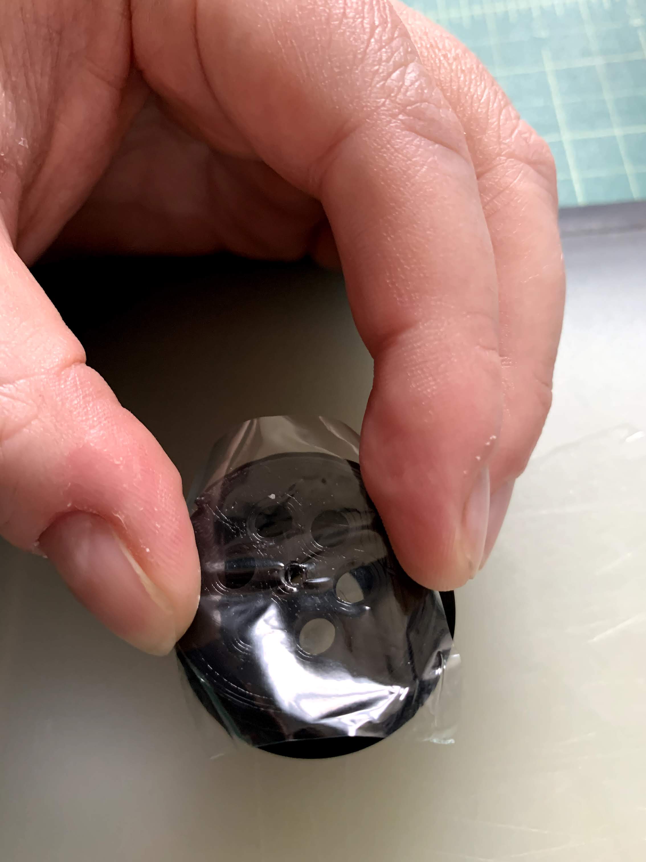
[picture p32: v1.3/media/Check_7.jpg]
Resulting Configuration


4. Insert the M3 screw, and using considerable downward pressure, screw it in flush and more than finger tight, using an appropriately sized allen (or other, depending on your M3 screw head configuration) wrench. If you find it is difficult to self-start and achieve purchase with the M3 screw, return to step 1 and widen the hole a bit more.

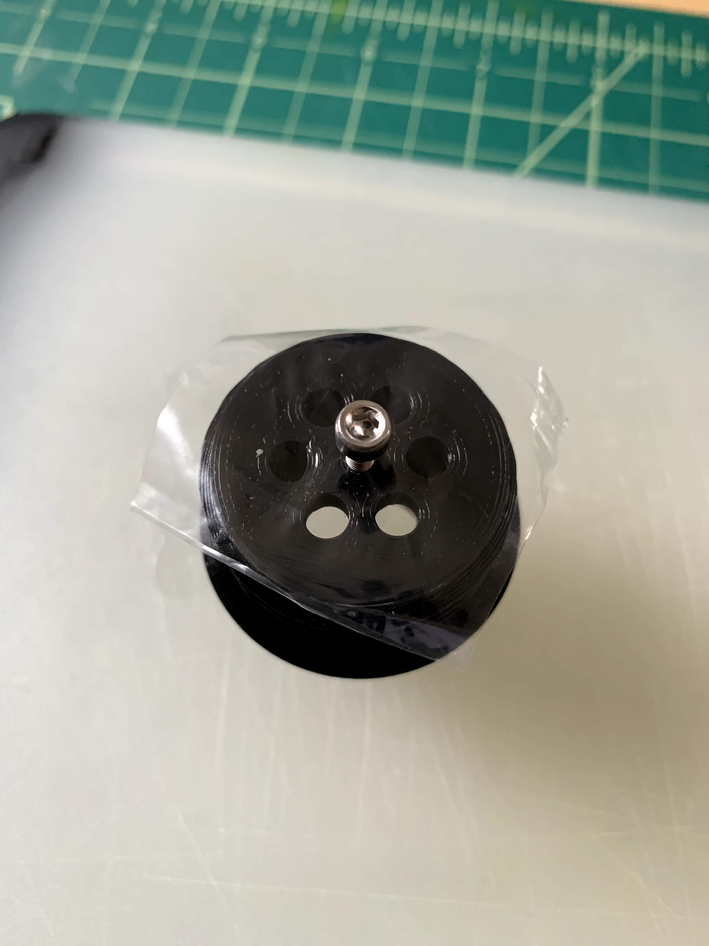
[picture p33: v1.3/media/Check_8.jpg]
Screw In M3


5. Trim the edges of the Ziploc plastic sheet so that it does not extend beyond the sides of the device.

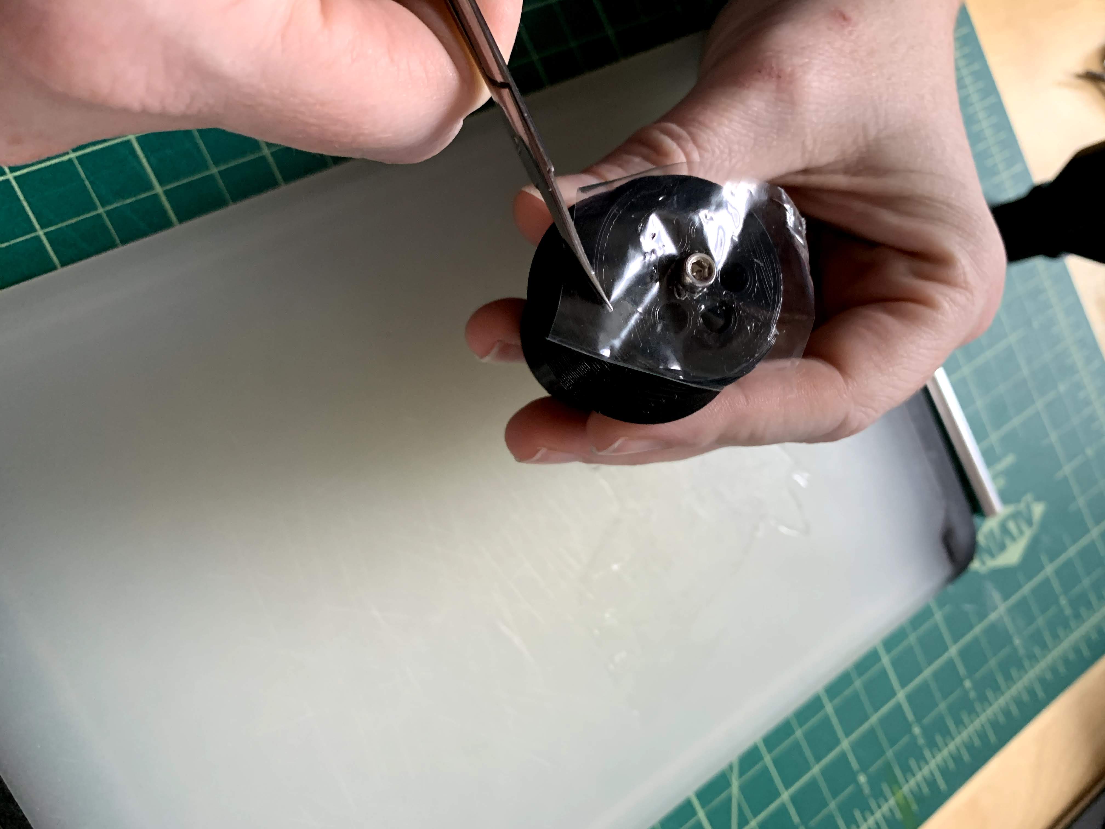
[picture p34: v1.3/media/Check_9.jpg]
Trim Plastic


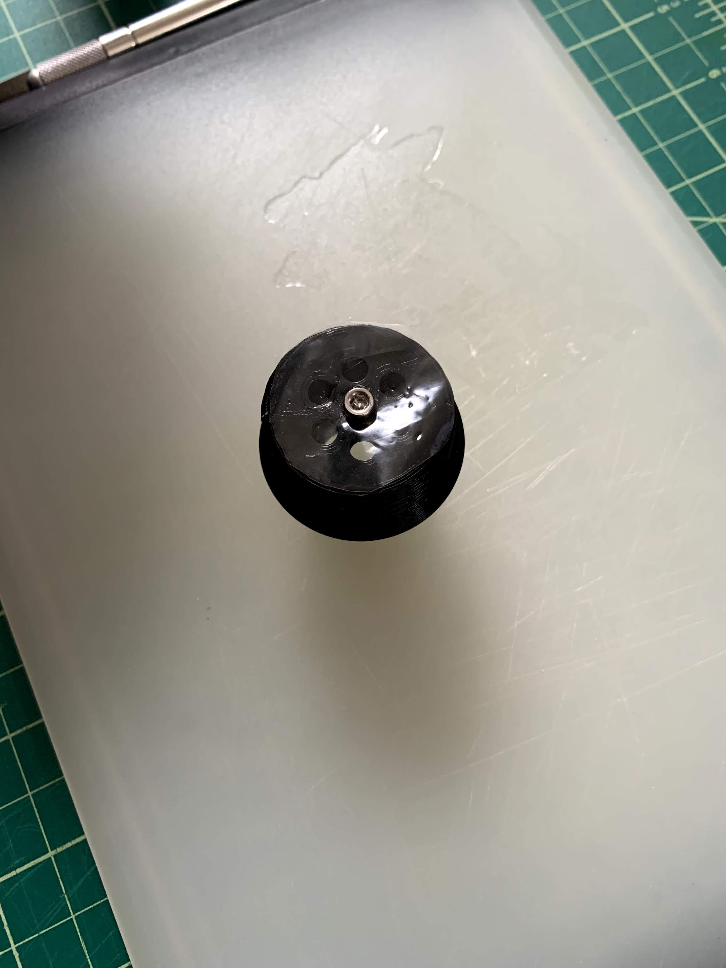
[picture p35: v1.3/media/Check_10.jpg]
Completed Baffle/Membrane


6. Finally, line the male screw threads in at least 2 layers of PTFE (Teflon) tape, and screw the device together, over hand tight.

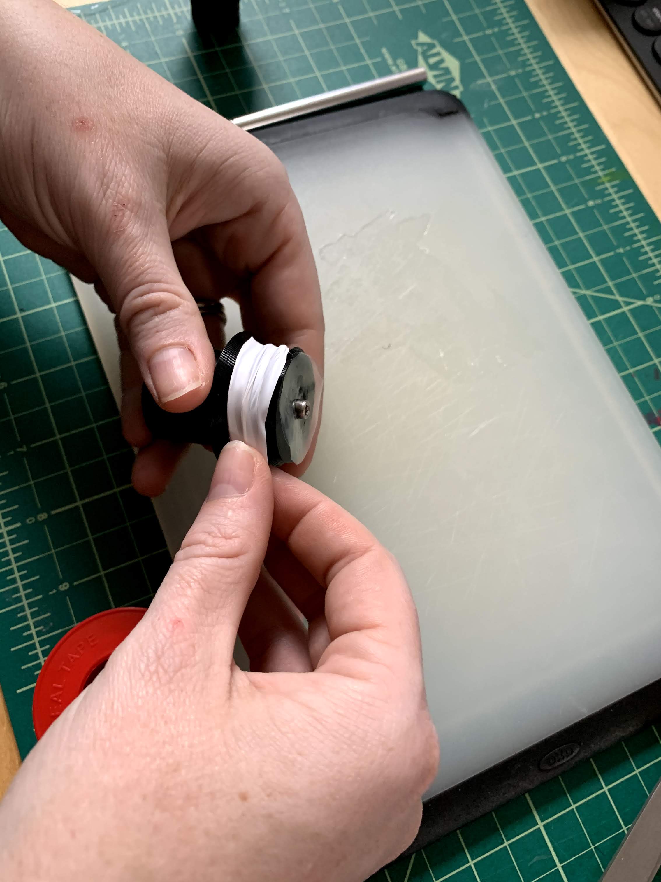
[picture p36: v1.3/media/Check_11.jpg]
Teflon Lining


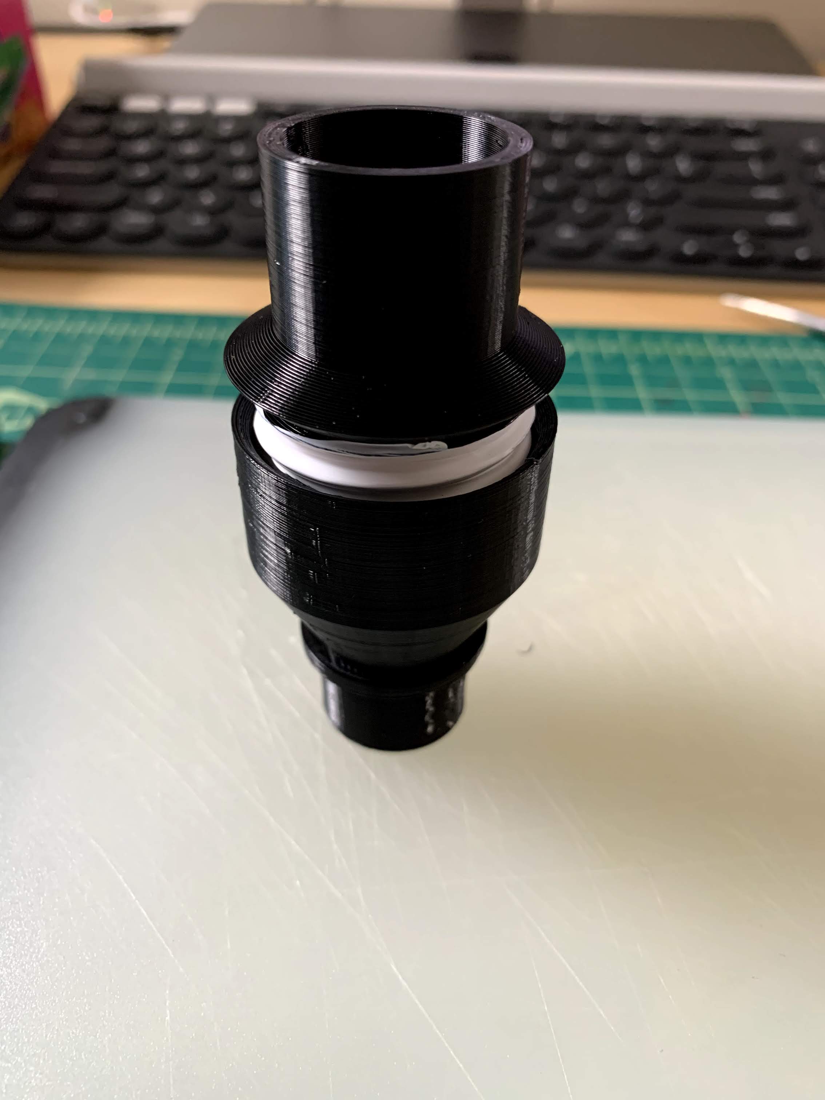
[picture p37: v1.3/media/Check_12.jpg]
Screw Tight


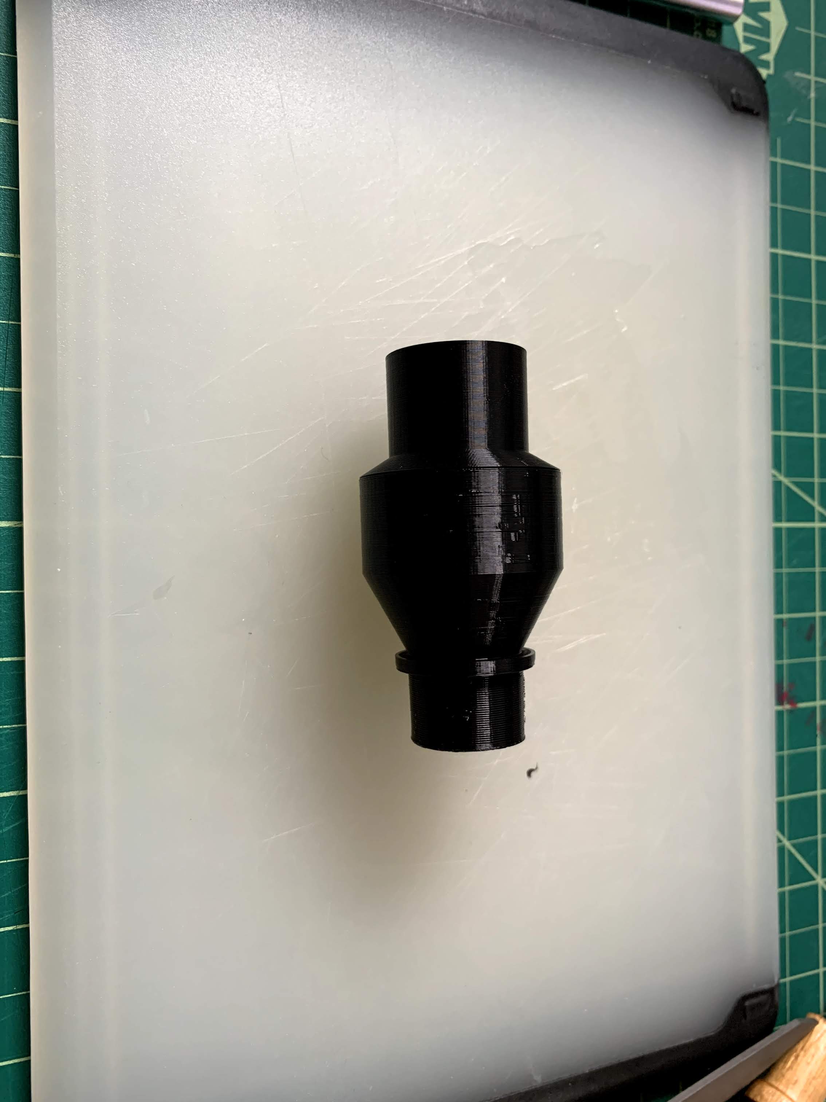
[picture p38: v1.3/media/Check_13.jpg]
Completed Check Valve


Congraulations! You've completed construction of the one-way check valve.

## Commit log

2020-03-28 initial commit with v2 components of valve and adapter
    [adapter_v2_largeFemaleFemale.stl, adapter_v2_smallMaleMale.stl, valve_v2_Female.stl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]
2020-03-29 Check Valve On Build Plate
    In correct orientation.
2020-03-30 organize into folders
    [adapter_v6_largeFemaleFemale.stl, adapter_v6_smallMaleMale.stl, valve_v6_Female.stl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]
2020-04-01 completely new versioning
    [adapter_v6_largeFemaleFemale.stl, adapter_v6_smallMaleMale.stl, valve_v6_Female.stl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]
2020-04-01 update file references
    [adapter_v1.2_largeFemaleFemale.stl, adapter_v1.2_smallMaleMale.stl, valve_v1.2_Female.stl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]
2020-04-01 add membrane cut files
    [plasticValveMembrane_v1.2.dxf]
2020-04-01 update to 1.3
    [adapter_v1.3_largeFemaleFemale.stl, adapter_v1.3_smallMaleMale.stl, plasticValveMembrane_v1.3.dxf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]
